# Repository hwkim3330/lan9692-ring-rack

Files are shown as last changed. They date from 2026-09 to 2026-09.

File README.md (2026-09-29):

# lan9692-ring-rack

LAN9692 링용 아크릴 랙. 9692가 3대이고, 한 대가 스택 하나의 바닥이다. 스택 3개는 모두 같은 구성이다.
판은 전부 **250 × 180 × 3 mm 투명 아크릴**이다. 이전(v1) 판과 외형, 기둥 위치, 9692 구멍, 팬 구멍이 같아서 서로 섞어 쓸 수 있다.

**3D 보기**
- 컬러 뷰어: <https://hwkim3330.github.io/lan9692-ring-rack/viewer/> (분해, 층 끄고 켜기, 아크릴 투명도 조절)
- [`stack.stl`](stack.stl): GitHub에서 누르면 돌려 볼 수 있다. 색이 없으니 포트 입구를 모양으로 파 뒀다

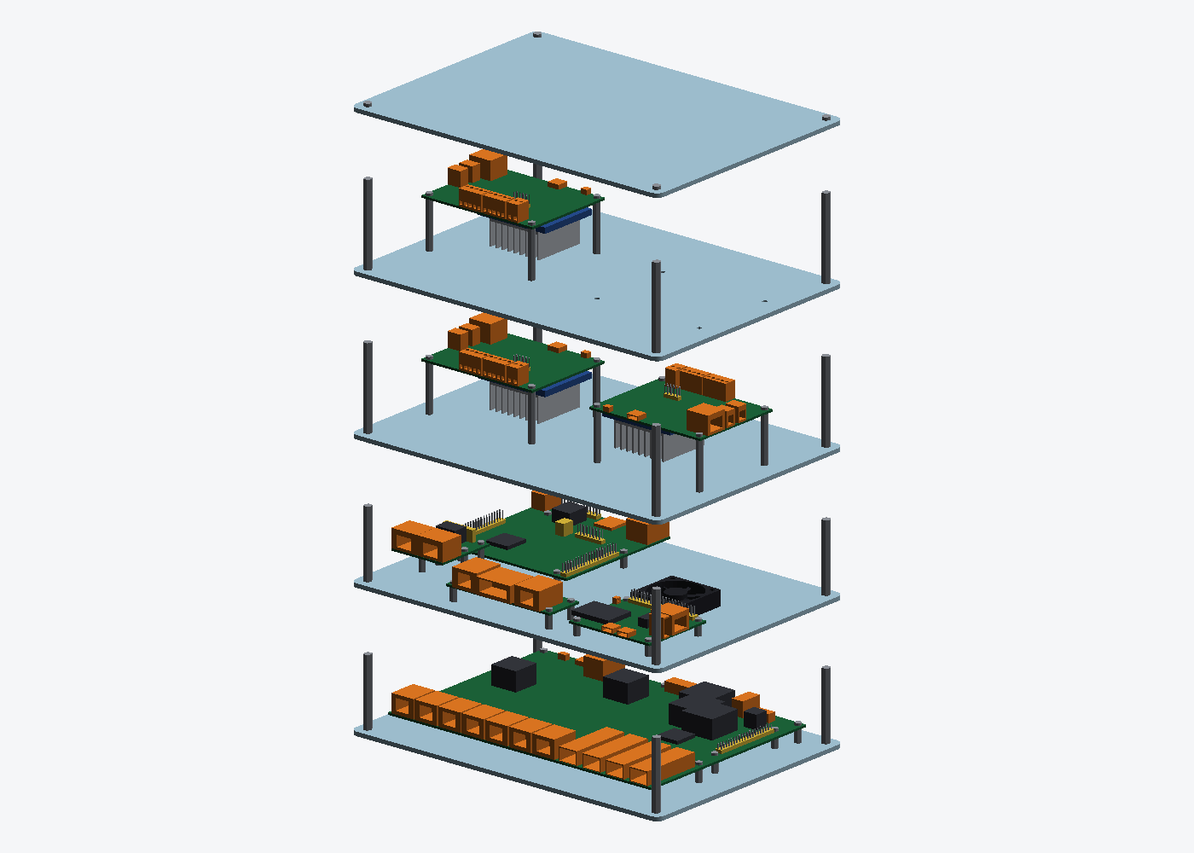
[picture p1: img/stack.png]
stack


| 층 | 판 | 올라가는 것 | 위층까지 |
|---|---|---|---:|
| 1 | `A-base` | LAN9692 (스탠드오프 10 mm) | 50 mm |
| 2 | `B-ecu` | TC397 · ESP32-S31 · 인젝션 모듈(RJ45 v2) · T1 커넥터 젠더 · 9692 팬 | 50 mm |
| 3 | `C-can` | CAN 보드 2장 (스탠드오프 35 mm) | 60 mm |
| 4 | `C-can` | CAN 보드 1장 (한 자리 여유) | 60 mm |
| 5 | `D-top` | 덮개 | — |

- 한 스택의 높이는 239 mm다(나사 머리 포함).
- **주문서: [`ORDER.md`](ORDER.md)** (아크릴 + 스탠드오프·나사·팬·전원 전부, [`BOM.csv`](BOM.csv)). 레이저 커팅은 [`order-dxf.zip`](order-dxf.zip)을 보낸다. 스택 3개 기준 총 15장이다.
  - A · B · D 각 3장
  - C 6장
- CAN 보드가 2장이면 `rack.py`의 `STACK`에서 `C-can` 하나를 빼면 된다. 그러면 12장이다.
- 레이저 커팅은 DXF로 주문한다. STL로는 주문하지 않는다.

## 배치

| 2층 | 3 · 4층 |
|---|---|
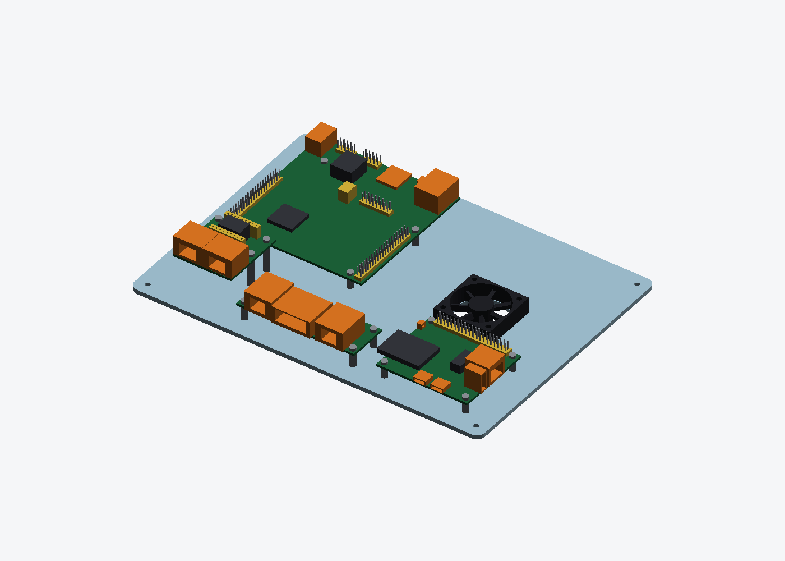
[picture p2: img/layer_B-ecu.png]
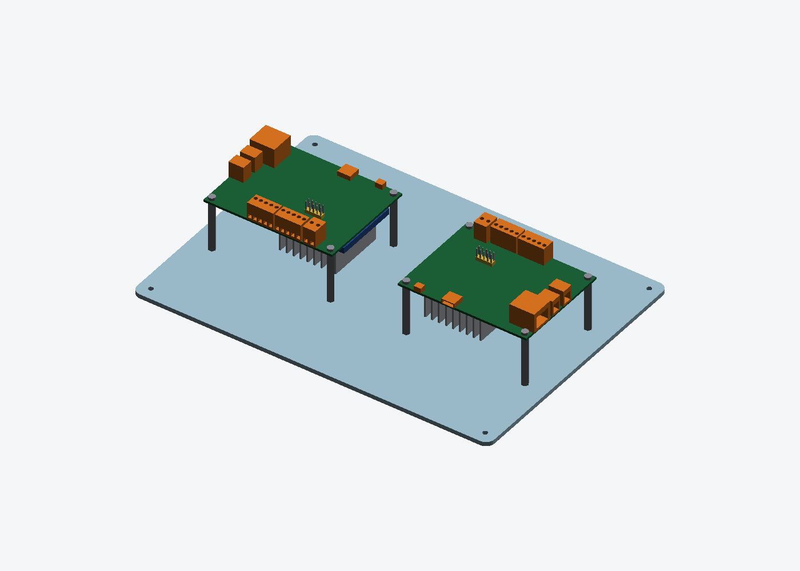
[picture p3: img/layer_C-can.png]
|  |  |

주황은 옆에서 꽂는 포트다. 입구가 커넥터 몸체에 파여 있어서, 색이 없는 STL에서도 어느 쪽으로 꽂는지 보인다. 노랑은 위에서 꽂는 헤더다.

**2층**
- TC397: POWER · SD · USB · RJ45가 뒤쪽 가장자리로 나간다. LIN · CAN은 위에서 꽂는 2x5 헤더다.
- 인젝션 모듈: 90° 돌려 놓아서 RJ45 2개가 앞쪽을 본다.
- T1 커넥터 젠더: 앞쪽 가운데 빈자리에 놓았다. MATEnet 2개와 TE 2305987-1이 앞쪽 가장자리로 나간다.
- ESP32-S31: USB-C 2개가 앞쪽, RJ45 · USB-A가 오른쪽을 본다. 모듈 안테나가 보드 왼쪽 밖으로 6 mm 나와 있어서 그 앞은 비워 뒀다.
- 팬: 9692 스위치 칩 바로 위, 판 구멍 자리에 있다.

**3 · 4층**
- CAN 보드는 세 면에 커넥터가 있다.
  - 왼쪽 면: CAN · LIN · POWER
  - 위쪽 면: ETH0 · T1S
  - 오른쪽 면: USB-C · RESET (실크의 A1…B8 핀 표기로 확인)
- 커넥터가 없는 면은 아래 면 하나뿐이다.
- 한 판에 두 장을 놓고, 빈 면끼리 46 mm 떨어져 마주 보게 했다. 그래서 **모든 커넥터가 판 가장자리로 나간다.**

| CAN 보드 | CAN · LIN · POWER | ETH · T1S | USB-C |
|---|---|---|---|
| 왼쪽 | 앞쪽 가장자리 | 왼쪽 가장자리 | 뒤쪽 가장자리 |
| 오른쪽 | 뒤쪽 가장자리 | 오른쪽 가장자리 | 앞쪽 가장자리 |

- 보드 밑에는 SoM과 20 mm 핀 방열판이 있다. 스탠드오프가 35 mm라 방열판 끝이 판에서 7.8 mm 떠 있다.

**검사**: `rack.py`는 모든 포트 앞으로 40 mm(가장자리가 더 가까우면 가장자리까지)를 쓸어서, 다른 보드·기둥·팬에 막히는지 본다. 지금 배치에서는 전부 통과한다. 보드 간격, 구멍 사이 아크릴 두께, 층별 높이 여유도 함께 검사한다.

## 치수 출처

모델은 보드 외형, 고정 구멍, 커넥터 블록까지만 그린다.

| 보드 | 출처 |
|---|---|
| LAN9692 EVB | Microchip Gerber/드릴(구멍), PnP(부품 위치) |
| TC397 AppKit | Infineon Application Kit Manual 그림 7-8(구멍), 그림 2-2(커넥터, ±0.5 mm) |
| ESP32-S31-Function-CoreBoard-1 | [Espressif 치수 DXF](https://dl.espressif.com/schematics/esp32-s31-function-coreboard-1-dimensions.dxf) |
| CAN 보드, 인젝션 모듈, T1 커넥터 젠더 | 각 보드의 제작 파일(KiCad) |

부품 높이 중 일부는 추정값이다. `boards.py`에서 `assumed`로 표시해 뒀다. 추정값이 틀려도 위층까지 5 mm 이상 여유가 남는다.

## 9692에서 5 V 따기

J4(2x20 확장 헤더)의 2번 · 4번 핀이 5 V다. 두 핀은 같은 레일이고, 둘을 합쳐 2 A까지 쓸 수 있다. 3.3 V는 1번 · 17번 핀, 2 A다. 출처는 EVB-LAN9692-LM User's Guide DS50003848, 표 5-14와 5.7절이다.

## 다시 만들기

```bash
pip3 install --break-system-packages trimesh shapely numpy pillow
python3 rack.py            # 검사 → DXF · zip → stack.stl · viewer/stack.glb → PNG
```

배치는 `rack.py`의 `PLATES`, 층 구성은 `STACK`에서 바꾼다.

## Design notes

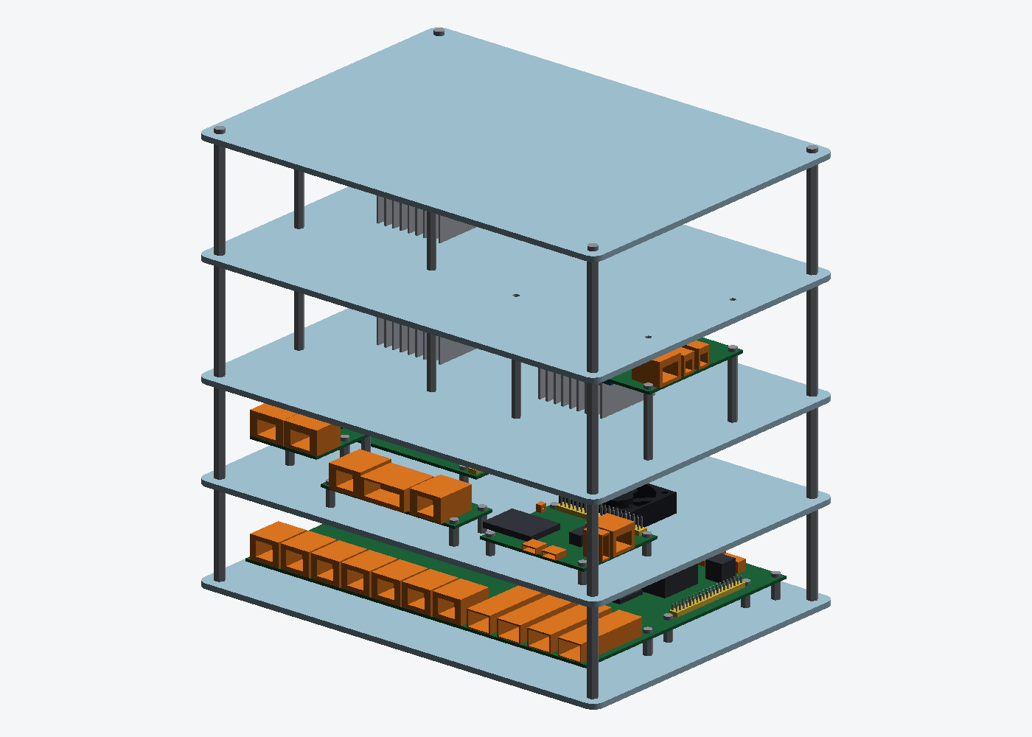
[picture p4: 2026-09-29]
img/stack_closed.png

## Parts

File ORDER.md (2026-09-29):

# 주문서 - 스택 3개

이 파일은 `rack.py`가 배치에서 직접 세어서 만든다. 손으로 고치지 말 것.

## 1. 레이저 커팅 (아크릴)

- 재질: **투명 캐스트 아크릴 3 mm**, 양면 보호필름 붙은 채로
- 판: **250 × 180 mm**, 모서리 R6. 도면은 DXF(mm, R12), 레이어 `CUT`만 있다
- 구멍 공차: 지름 +0.1 / -0 (M3 → Ø3.4, M2.5 → Ø2.9)
- 보낼 파일: `order-dxf.zip` 하나

| 도면 | 수량 | 구멍 |
|---|---:|---:|
| `dxf/A-base.dxf` | 3 | 12 |
| `dxf/B-ecu.dxf` | 3 | 25 |
| `dxf/C-can.dxf` | 6 | 12 |
| `dxf/D-top.dxf` | 3 | 4 |
| **합계** | **15** | |

## 2. 하드웨어

| 구분 | 품목 | 규격 | 수량 | 메모 |
|---|---|---|---:|---|
| column | hex standoff M/F | M3 x 50, male 6 mm | 24 | male end up; the stud crosses the plate above into the next standoff |
| column | hex standoff M/F | M3 x 60, male 6 mm | 24 | male end up; the stud crosses the plate above into the next standoff |
| column | screw, pan head | M3 x 8 | 12 | up through plate A into the first column standoff |
| column | nut | M3 | 12 | on the four studs above the top plate |
| column | rubber foot | self-adhesive, ~10 mm | 12 | under plate A |
| boards | hex standoff F/F | M3 x 10 | 24 | LAN9692 (board drill Ø3.048 - try an M3 by hand, use M2.5 if it binds) |
| boards | screw, pan head | M3 x 6 | 84 | down through the board |
| boards | screw, pan head | M3 x 8 | 84 | up through the plate |
| boards | washer, nylon | M3 | 84 | under every screw head that lands on acrylic |
| boards | hex standoff F/F | M3 x 8 | 24 | TC397, ESP32-S31 |
| boards | hex standoff F/F | M2.5 x 20 | 12 | FIM-RJ45v2 |
| boards | screw, pan head | M2.5 x 6 | 24 | down through the board |
| boards | screw, pan head | M2.5 x 8 | 24 | up through the plate |
| boards | washer, nylon | M2.5 | 24 | under every screw head that lands on acrylic |
| boards | hex standoff F/F | M2.5 x 10 | 12 | T1-Gender |
| boards | hex standoff F/F | M3 x 35 | 36 | KA7-UNO |
| fan | fan | 40 x 40 x 10 mm, 12 V | 3 | Noctua NF-A4x10 FLX; 32 mm hole pitch |
| fan | screw, pan head | M3 x 20 | 12 | down through the fan and plate B |
| fan | nut, nyloc | M3 | 12 | the fan is the one part that vibrates |
| power | DC adapter | 12 V 5 A, 5.5 x 2.5 mm, centre + | 3 | Mean Well GST60A12-P1M (P1M = 2.5 mm; P1J is 2.1 and contacts badly) |
| power | DC splitter | 1 female -> 2 male, 5.5 x 2.5 mm | 3 | NOT 5.5 x 2.1 |
| power | barrel socket to leads | female 5.5 x 2.5, 18 AWG | 3 | Tensility 10-02879 - the fan joins here. Meter which lead is the centre pin |

여분: 나사·너트·와셔는 10 % 더 사는 게 좋다. M3 x 60 스탠드오프가 없으면 30 + 30으로 이어도 된다.

## 3. 이미 있는 것 (주문 안 함)

- CAN 보드 방열판 20 mm (이미 붙어 있음)
- 보드 자체: LAN9692 EVB, TC397, ESP32-S31, CAN 보드, 인젝션 모듈 v2, T1 커넥터 젠더

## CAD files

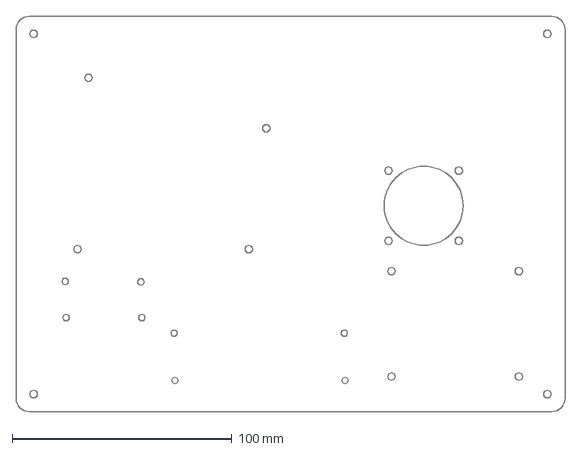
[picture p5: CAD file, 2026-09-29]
dxf/B-ecu.dxf
250.0 x 180.0 mm

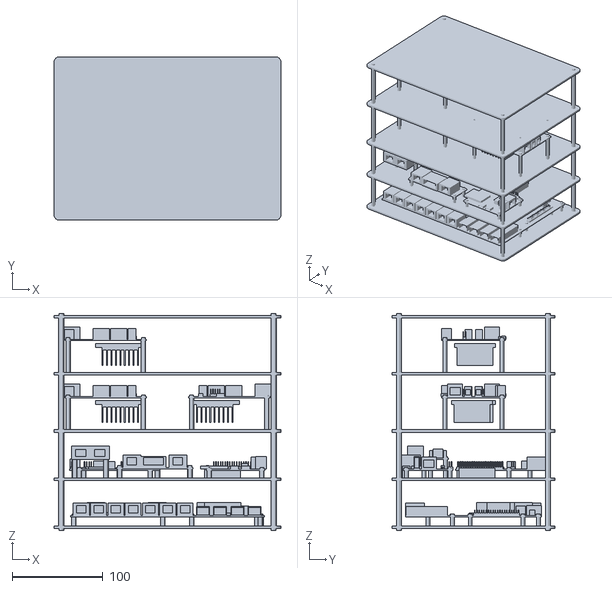
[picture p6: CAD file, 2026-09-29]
stack.stl
250.0 x 180.0 x 239.4

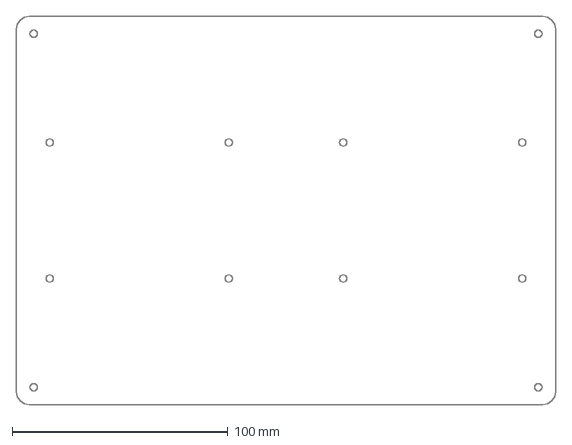
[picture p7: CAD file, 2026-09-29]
dxf/C-can.dxf
250.0 x 180.0 mm

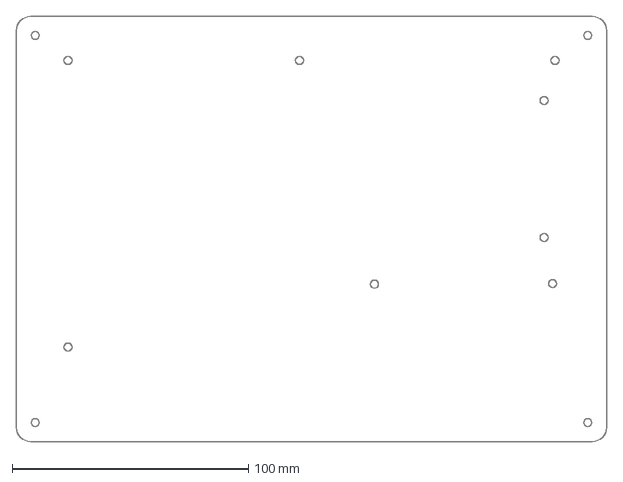
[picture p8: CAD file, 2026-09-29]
dxf/A-base.dxf
250.0 x 180.0 mm

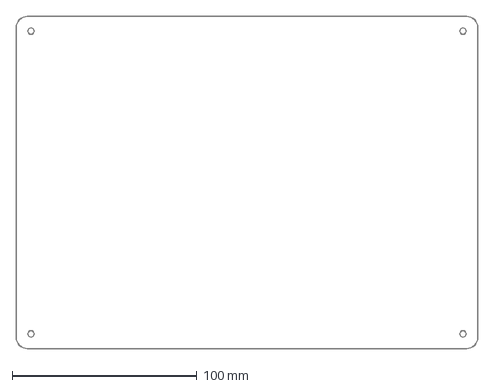
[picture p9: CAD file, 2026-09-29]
dxf/D-top.dxf
250.0 x 180.0 mm

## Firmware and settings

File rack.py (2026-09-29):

#!/usr/bin/env python3
"""Three acrylic stacks for the LAN9692 ring, one switch at the base of each.

    python3 rack.py            checks, DXF + order zip, STL, PNG
    python3 rack.py --no-png   skip the (slow) renders

Every plate is the same 250 x 180 x 3 mm clear acrylic with the same four
corner columns, so any upper plate bolts onto any stack. What a stack carries
is which plates you stack on it - see STACKS.
"""
import math
import os
import sys
import zipfile

import numpy as np
import trimesh
from shapely.geometry import Point, box
from shapely.ops import unary_union

import boards as B
import parts3d as P3
from render import render

HERE = os.path.dirname(os.path.abspath(__file__))

# --------------------------------------------------------------------------
# plate
PW, PH, T = 250.0, 180.0, 3.0      # the v1 plate - fixed, everything has to fit it
PLATE_R = 6.0
COLUMN_INSET = 8.0
M3 = 3.4
COLUMN_KEEPOUT = 6.0              # M3 M/F standoff, 5.5 mm across flats, + a hand
FAN = 40.0                        # Noctua NF-A4x10 on top of B, blowing down
FAN_H = 11.0
FAN_BORE = 36.0
FAN_PITCH = 32.0
BOARD_OFF = ((PW - B.LAN9692['size'][0]) / 2, (PH - B.LAN9692['size'][1]) / 2)
FAN_C = (BOARD_OFF[0] + B.LAN_U1[0], BOARD_OFF[1] + B.LAN_U1[1])

# --------------------------------------------------------------------------
# what goes on each plate: (board, cx, cy, rot CCW)
PLATES = {
    'A-base': [('LAN9692', PW / 2, PH / 2, 0)],
    # layer 2: TC397 connector row to the back rim; the injection module turned
    # so its two RJ45s face the front rim; the S31's USB-C to the front and
    # its RJ45/USB-A to the right rim; the 9692's fan over the switch die
    'B-ecu': [('TC397', 67.0, 120.0, 0),
              ('FIM-RJ45v2', 40.0, 40.0, 90),
              ('ESP32-S31', 200.0, 40.0, 0),
              # the T1 connector gender in the front gap, its three TE headers
              # to the front rim
              ('T1-Gender', 111.0, 25.0, 0)],
    # layer 3: two CAN boards per plate. The board has connectors on three
    # edges and one free one, so the two turn their free edges to each other
    # and every connector reaches a rim:
    #   left   CAN/LIN/POWER front, ETH/T1S left,  USB-C back
    #   right  CAN/LIN/POWER back,  ETH/T1S right, USB-C front
    'C-can': [('KA7-UNO', 57.0, 90.0, 90),
              ('KA7-UNO', 193.0, 90.0, 270)],
    'D-top': [],
}
FAN_ON = {'B-ecu'}

# layer gap above each plate kind (plate top to the next plate's underside)
GAP = {'A-base': 50.0, 'B-ecu': 50.0, 'C-can': 60.0}

STACK = ['A-base', 'B-ecu', 'C-can', 'C-can', 'D-top']   # bottom to top
FITTED = {3: [0]}                 # level -> boards fitted; the second CAN plate
                                  # carries the third board, room for a fourth
N_STACKS = 3                      # one per LAN9692 in the ring, all the same
PLUG_ROOM = 40.0                  # clear space a port needs in front of it,
                                  # or the rim if that is closer

MIN_GAP = 5.0                     # board to board, in plan
MIN_WEB = 2.5                     # acrylic between two cuts. The fan bore to its own
                                  # screw holes is 2.93, as cut and fitted in v1
MIN_AIR = 5.0                     # vertical


# --------------------------------------------------------------------------
# placement
def transform(board, cx, cy, rot):
    w, h = B.BOARDS[board]['size']
    c, s = round(math.cos(math.radians(rot))), round(math.sin(math.radians(rot)))

    def f(x, y):
        u, v = x - w / 2, y - h / 2
        return cx + c * u - s * v, cy + s * u + c * v
    return f


FACE_ROT = {0: {}, 90: {'-x': '-y', '-y': '+x', '+x': '+y', '+y': '-x'},
            180: {'-x': '+x', '+x': '-x', '-y': '+y', '+y': '-y'},
            270: {'-x': '+y', '+y': '+x', '+x': '-y', '-y': '-x'}}


def rect(f, x0, y0, x1, y1):
    (ax, ay), (bx, by) = f(x0, y0), f(x1, y1)
    return (min(ax, bx), min(ay, by), max(ax, bx), max(ay, by))


def placed(kind):
    """-> list of dict(board, pcb, parts[(name, rect, h, face)], holes[(x,y,d)])"""
    out = []
    for board, cx, cy, rot in PLATES[kind]:
        d = B.BOARDS[board]
        f = transform(board, cx, cy, rot)
        w, h = d['size']
        parts = [(n, rect(f, x0, y0, x1, y1), ht,
                  FACE_ROT[rot].get(face, face) if face else None, src)
                 for n, x0, y0, x1, y1, ht, face, src in d['parts']]
        out.append(dict(board=board, rot=rot, pcb=rect(f, 0, 0, w, h), parts=parts,
                        under=[(n, rect(f, x0, y0, x1, y1), zt, zb)
                               for n, x0, y0, x1, y1, zt, zb in d['under']],
                        holes=[f(x, y) + (d['hole_d'],) for x, y in d['holes']],
                        f=f))
    return out


def columns():
    return [(x, y) for x in (COLUMN_INSET, PW - COLUMN_INSET)
            for y in (COLUMN_INSET, PH - COLUMN_INSET)]


def features(kind):
    """Every circle cut in a plate: (x, y, d)."""
    f = [(x, y, M3) for x, y in columns()]
    if kind in FAN_ON:
        f.append((FAN_C[0], FAN_C[1], FAN_BORE))
        f += [(FAN_C[0] + sx * FAN_PITCH / 2, FAN_C[1] + sy * FAN_PITCH / 2, M3)
              for sx in (-1, 1) for sy in (-1, 1)]
    for p in placed(kind):
        f += p['holes']
    return f


# --------------------------------------------------------------------------
# checks
def footprint(p):
    return unary_union([box(*p['pcb'])] + [box(*r) for _, r, *_ in p['parts']]
                       + [box(*r) for _, r, *_ in p['under']])


def check_plate(kind):
    rows, ports = [], []
    ps = placed(kind)
    plate = box(0, 0, PW, PH)
    keep = [Point(x, y).buffer(COLUMN_KEEPOUT) for x, y in columns()]
    fan = box(FAN_C[0] - FAN / 2, FAN_C[1] - FAN / 2, FAN_C[0] + FAN / 2,
              FAN_C[1] + FAN / 2) if kind in FAN_ON else None

    def need(label, mm, want):
        rows.append((label, mm, want, mm >= want))

    fps = [footprint(p) for p in ps]
    for i in range(len(ps)):
        name = f"{ps[i]['board']}#{i}"
        need(f'{name} inside the plate', min(
            fps[i].bounds[0], fps[i].bounds[1], PW - fps[i].bounds[2], PH - fps[i].bounds[3]), 0.0)
        need(f'{name} to the corner columns', min(fps[i].distance(k) for k in keep), 0.0)
        if fan is not None:
            need(f'{name} to the fan', fps[i].distance(fan), MIN_GAP)
        for j in range(i + 1, len(ps)):
            need(f"{name} to {ps[j]['board']}#{j}", fps[i].distance(fps[j]), MIN_GAP)
    # acrylic webs
    cuts = features(kind)
    worst = min((math.hypot(a[0] - b[0], a[1] - b[1]) - a[2] / 2 - b[2] / 2)
                for i, a in enumerate(cuts) for b in cuts[i + 1:])
    need('thinnest web between two holes', worst, MIN_WEB)
    need('thinnest web to the plate edge',
         min(min(x, y, PW - x, PH - y) - d / 2 for x, y, d in cuts), MIN_WEB)
    # ports: sweep each port's face out to the rim and see what it meets
    for i, p in enumerate(ps):
        others = [fps[j] for j in range(len(ps)) if j != i] + keep + ([fan] if fan else [])
        for n, (x0, y0, x1, y1), h, face, src in p['parts']:
            if face in (None, 'top'):
                continue
            to_rim = {'-x': x0, '+x': PW - x1, '-y': y0, '+y': PH - y1}[face]
            r = min(PLUG_ROOM, max(to_rim, 0.0))
            lane = {'-x': (x0 - r, y0, x0, y1), '+x': (x1, y0, x1 + r, y1),
                    '-y': (x0, y0 - r, x1, y0), '+y': (x0, y1, x1, y1 + r)}[face]
            if lane[2] - lane[0] <= 0 or lane[3] - lane[1] <= 0:
                blocked = False             # already at or past the rim
            else:
                blocked = any(box(*lane).intersects(o) for o in others)
            ports.append((f"{p['board']}#{i} {n}", face, to_rim, not blocked))
    return rows, ports


def vertical(kind):
    """Clearances in the layer ABOVE this plate, and under its boards."""
    rows = []
    gap = GAP.get(kind)
    for i, p in enumerate(placed(kind)):
        d = B.BOARDS[p['board']]
        top = d['standoff'] + B.PCB_T + max(h for _, _, _, _, _, h, _, _ in d['parts'])
        if gap:
            rows.append((f"{p['board']}#{i} tallest part -> plate above", gap - top, MIN_AIR))
        for n, _, _, zb in p['under']:
            rows.append((f"{p['board']}#{i} {n} -> its own plate", d['standoff'] - zb, MIN_AIR))
    if kind in FAN_ON:
        rows.append(('fan -> plate above', gap - FAN_H, MIN_AIR))
    if kind == 'A-base':
        rows.append(('LAN9692 tallest part -> fan underside',
                     gap - B.LAN9692['standoff'] - B.PCB_T - 14.0, MIN_AIR))
    return [(l, mm, w, mm >= w) for l, mm, w in rows]


def run_checks(verbose=True):
    ok = True
    for kind in PLATES:
        rows, ports = check_plate(kind)
        rows += vertical(kind)
        bad = [r for r in rows if not r[3]] + [p for p in ports if not p[3]]
        ok &= not bad
        if not verbose:
            continue
        print(f'\n{kind}: {"OK" if not bad else "FAIL"}')
        for label, mm, want, good in rows:
            print(f'    {label:52s} {mm:8.2f}  >= {want:<4}' + ('' if good else '  <-- FAIL'))
        for label, face, to_rim, clear in ports:
            print(f'    port {label:40s} {face:>3}  {to_rim:6.1f} mm to rim  '
                  + ('clear' if clear else 'BLOCKED'))
    return ok


# --------------------------------------------------------------------------
# DXF
class Dxf:
    def __init__(self):
        self.e = []

    def line(self, x1, y1, x2, y2):
        self.e.append(f"0\nLINE\n8\nCUT\n10\n{x1:.4f}\n20\n{y1:.4f}\n30\n0.0\n"
                      f"11\n{x2:.4f}\n21\n{y2:.4f}\n31\n0.0\n")

    def arc(self, cx, cy, r, a0, a1):
        self.e.append(f"0\nARC\n8\nCUT\n10\n{cx:.4f}\n20\n{cy:.4f}\n30\n0.0\n"
                      f"40\n{r:.4f}\n50\n{a0:.4f}\n51\n{a1:.4f}\n")

    def circle(self, cx, cy, r):
        self.e.append(f"0\nCIRCLE\n8\nCUT\n10\n{cx:.4f}\n20\n{cy:.4f}\n30\n0.0\n40\n{r:.4f}\n")

    def rounded_rect(self, w, h, r):
        self.line(r, 0, w - r, 0); self.line(r, h, w - r, h)
        self.line(0, r, 0, h - r); self.line(w, r, w, h - r)
        self.arc(w - r, h - r, r, 0, 90); self.arc(r, h - r, r, 90, 180)
        self.arc(r, r, r, 180, 270); self.arc(w - r, r, r, 270, 360)

    def save(self, path):
        with open(path, 'w') as f:
            f.write("0\nSECTION\n2\nHEADER\n9\n$INSUNITS\n70\n4\n0\nENDSEC\n"
                    "0\nSECTION\n2\nENTITIES\n" + ''.join(self.e) + "0\nENDSEC\n0\nEOF\n")


def write_dxf(kind, path):
    d = Dxf()
    d.rounded_rect(PW, PH, PLATE_R)
    for x, y, dia in features(kind):
        d.circle(x, y, dia / 2)
    d.save(path)


# --------------------------------------------------------------------------
# 3D
COL = {'plate': (170, 205, 222), 'pcb': (30, 105, 60), 'port': (235, 125, 35),
       'top': (225, 190, 60), 'part': (55, 57, 64), 'som': (40, 80, 150),
       'sink': (190, 195, 202), 'metal': (150, 155, 162), 'fan': (35, 36, 42),
       'ka7': (30, 105, 60)}


def tagged(m, c):
    m.visual.face_colors = np.tile(np.array(list(COL[c]) + [255], np.uint8), (len(m.faces), 1))
    return m


def slab(r, z0, z1, c):
    x0, y0, x1, y1 = r
    m = trimesh.creation.box(extents=(x1 - x0, y1 - y0, z1 - z0))
    m.apply_translation(((x0 + x1) / 2, (y0 + y1) / 2, (z0 + z1) / 2))
    return tagged(m, c)


def post(x, y, z0, z1, d=5.5):
    m = trimesh.creation.cylinder(radius=d / 2, height=z1 - z0, sections=6)
    m.apply_translation((x, y, (z0 + z1) / 2))
    return tagged(m, 'metal')


def plate_poly(kind):
    r = PLATE_R
    outline = box(r, r, PW - r, PH - r).buffer(r, resolution=16)
    return outline.difference(unary_union(
        [Point(x, y).buffer(d / 2, resolution=24) for x, y, d in features(kind)]))


def plate_mesh(kind, z):
    m = trimesh.creation.extrude_polygon(plate_poly(kind), T)
    m.apply_translation((0, 0, z))
    return tagged(m, 'plate')


def board_meshes(p, z_plate_top, detail=True):
    d = B.BOARDS[p['board']]
    zp = z_plate_top + d['standoff']
    top = zp + B.PCB_T
    out = [slab(p['pcb'], zp, top, 'pcb')]
    for n, r, h, face, src in p['parts']:
        if face == 'top':
            bars, pins = P3.header(n, r, top, h)
            out += [tagged(m, 'top') for m in bars] + [tagged(m, 'metal') for m in pins]
        elif face:
            out += [tagged(m, 'port') for m in P3.side_connector(n, r, top, h, face)]
        else:
            out.append(slab(r, top, top + h, 'part'))
    for n, r, zt, zb in p['under']:
        if 'heatsink' in n:
            out += [tagged(m, 'sink') for m in P3.heatsink(r, zp - zt, zp - zb)]
        else:
            out.append(slab(r, zp - zb, zp - zt, 'som'))
    for x, y, _ in p['holes']:
        out.append(post(x, y, z_plate_top, zp, d=5.0))
        out.append(tagged(P3.screw_head(x, y, top, d=4.6, hh=1.8), 'metal'))
    return out


def layer_meshes(kind, z, detail=True, fitted=None):
    """-> [(group, mesh)]; group names what the viewer can hide or tint."""
    parts = [('plate', plate_mesh(kind, z))]
    if kind in FAN_ON:
        parts += [('fan', tagged(m, 'fan')) for m in P3.fan(FAN_C[0], FAN_C[1], z + T, FAN, FAN_H)]
    for i, p in enumerate(placed(kind)):
        if fitted is None or i in fitted:
            parts += [(p['board'], m) for m in board_meshes(p, z + T)]
    return parts


def stack_parts(explode=0.0):
    """-> [(level, group, mesh)] for the whole stack, bottom to top."""
    parts, z = [], 0.0
    for lvl, kind in enumerate(STACK):
        parts += [(lvl, g, m) for g, m in layer_meshes(kind, z, fitted=FITTED.get(lvl))]
        if kind in GAP:
            nxt = z + T + GAP[kind]
            for x, y in columns():
                parts.append((lvl, 'column', post(x, y, z + T, nxt, d=6.0)))
            z = nxt + explode
        else:
            for x, y in columns():
                parts.append((lvl, 'column', tagged(P3.screw_head(x, y, z + T), 'metal')))
    for x, y in columns():
        parts.append((0, 'column', tagged(P3.screw_head(x, y, 0.0, up=False), 'metal')))
    return parts


def stack_mesh(explode=0.0):
    return trimesh.util.concatenate([m for _, _, m in stack_parts(explode)])


def export_glb(path):
    """One node per (level, group, colour), so the viewer can explode and tint."""
    scene = trimesh.Scene()
    groups = {}
    for lvl, g, m in stack_parts():
        c = tuple(m.visual.face_colors[0][:3])
        groups.setdefault((lvl, g, c), []).append(m)
    for (lvl, g, c), ms in groups.items():
        m = trimesh.util.concatenate(ms)
        m.visual = trimesh.visual.TextureVisuals(material=trimesh.visual.material.PBRMaterial(
            baseColorFactor=[c[0] / 255, c[1] / 255, c[2] / 255, 1.0],
            metallicFactor=0.6 if g in ('column',) else 0.0, roughnessFactor=0.55))
        scene.add_geometry(m, node_name=f'L{lvl}|{g}|{c[0]}_{c[1]}_{c[2]}',
                           geom_name=f'L{lvl}|{g}|{c[0]}_{c[1]}_{c[2]}')
    scene.export(path)


# --------------------------------------------------------------------------
# order: every screw, standoff and plate, counted from the layout itself
def bom():
    """-> [(group, item, spec, qty, note)] for N_STACKS stacks."""
    from collections import Counter
    c = Counter()
    notes = {}

    def add(group, item, spec, n, note=''):
        c[(group, item, spec)] += n * N_STACKS
        if note:
            notes[(group, item, spec)] = note

    for kind in PLATES:
        n = STACK.count(kind)
        if n:
            add('acrylic', f'plate {kind}', f'clear cast acrylic 3 mm, {PW:.0f} x {PH:.0f}, R{PLATE_R:.0f}',
                n, f'dxf/{kind}.dxf')
    # columns: M/F, male end up; each stud crosses the plate above it and
    # threads into the next standoff, so one hole per corner does both joints
    for kind in STACK:
        if kind in GAP:
            add('column', 'hex standoff M/F', f'M3 x {GAP[kind]:.0f}, male 6 mm', 4,
                'male end up; the stud crosses the plate above into the next standoff')
    add('column', 'screw, pan head', 'M3 x 8', 4, 'up through plate A into the first column standoff')
    add('column', 'nut', 'M3', 4, 'on the four studs above the top plate')
    add('column', 'rubber foot', 'self-adhesive, ~10 mm', 4, 'under plate A')
    # boards: F/F standoffs, a screw from under the plate and one from above
    for lvl, kind in enumerate(STACK):
        f = FITTED.get(lvl)
        for i, p in enumerate(placed(kind)):
            if f is not None and i not in f:
                continue
            d = B.BOARDS[p['board']]
            m = 'M2.5' if d['hole_d'] < 3.2 else 'M3'
            k = len(d['holes'])
            key = ('boards', 'hex standoff F/F', f"{m} x {d['standoff']:.0f}")
            who = notes.get(key, '')
            if p['board'] not in who:
                who = (who + ', ' if who else '') + p['board']
            if p['board'] == 'LAN9692':
                who += ' (board drill Ø3.048 - try an M3 by hand, use M2.5 if it binds)'
            add(*key, k, who)
            add('boards', 'screw, pan head', f'{m} x 6', k, 'down through the board')
            add('boards', 'screw, pan head', f'{m} x 8', k, 'up through the plate')
            add('boards', 'washer, nylon', m, k, 'under every screw head that lands on acrylic')
    # fan over the switch die, on top of the B plate
    add('fan', 'fan', '40 x 40 x 10 mm, 12 V', 1, 'Noctua NF-A4x10 FLX; 32 mm hole pitch')
    add('fan', 'screw, pan head', 'M3 x 20', 4, 'down through the fan and plate B')
    add('fan', 'nut, nyloc', 'M3', 4, 'the fan is the one part that vibrates')
    add('power', 'DC adapter', '12 V 5 A, 5.5 x 2.5 mm, centre +', 1,
        'Mean Well GST60A12-P1M (P1M = 2.5 mm; P1J is 2.1 and contacts badly)')
    add('power', 'DC splitter', '1 female -> 2 male, 5.5 x 2.5 mm', 1, 'NOT 5.5 x 2.1')
    add('power', 'barrel socket to leads', 'female 5.5 x 2.5, 18 AWG', 1,
        'Tensility 10-02879 - the fan joins here. Meter which lead is the centre pin')
    return [(g, i, s_, q, notes.get((g, i, s_), '')) for (g, i, s_), q in c.items()]


def write_order():
    rows = bom()
    with open(os.path.join(HERE, 'BOM.csv'), 'w') as f:
        f.write('group,item,spec,qty,note\n')
        for r in rows:
            f.write(','.join(f'"{x}"' if isinstance(x, str) and (',' in x) else str(x) for x in r) + '\n')
    md = [f'# 주문서 - 스택 {N_STACKS}개\n',
          f'이 파일은 `rack.py`가 배치에서 직접 세어서 만든다. 손으로 고치지 말 것.\n',
          '## 1. 레이저 커팅 (아크릴)\n',
          f'- 재질: **투명 캐스트 아크릴 3 mm**, 양면 보호필름 붙은 채로',
          f'- 판: **{PW:.0f} × {PH:.0f} mm**, 모서리 R{PLATE_R:.0f}. 도면은 DXF(mm, R12), 레이어 `CUT`만 있다',
          '- 구멍 공차: 지름 +0.1 / -0 (M3 → Ø3.4, M2.5 → Ø2.9)',
          '- 보낼 파일: `order-dxf.zip` 하나\n',
          '| 도면 | 수량 | 구멍 |', '|---|---:|---:|']
    for kind in PLATES:
        n = N_STACKS * STACK.count(kind)
        if n:
            md.append(f'| `dxf/{kind}.dxf` | {n} | {len(features(kind))} |')
    md.append(f'| **합계** | **{N_STACKS * len(STACK)}** | |\n')
    md.append('## 2. 하드웨어\n')
    md.append('| 구분 | 품목 | 규격 | 수량 | 메모 |')
    md.append('|---|---|---|---:|---|')
    for g, i, s_, q, n in rows:
        if g != 'acrylic':
            md.append(f'| {g} | {i} | {s_} | {q} | {n} |')
    md.append('\n여분: 나사·너트·와셔는 10 % 더 사는 게 좋다. M3 x 60 스탠드오프가 없으면 30 + 30으로 이어도 된다.\n')
    md.append('## 3. 이미 있는 것 (주문 안 함)\n')
    md.append('- CAN 보드 방열판 20 mm (이미 붙어 있음)')
    md.append('- 보드 자체: LAN9692 EVB, TC397, ESP32-S31, CAN 보드, 인젝션 모듈 v2, T1 커넥터 젠더\n')
    open(os.path.join(HERE, 'ORDER.md'), 'w').write('\n'.join(md))


# --------------------------------------------------------------------------
def main():
    for sub in ('dxf', 'img', 'viewer'):
        os.makedirs(os.path.join(HERE, sub), exist_ok=True)
    ok = run_checks()

    print(f'\norder: {N_STACKS} stacks, 250 x 180 x 3 mm clear acrylic')
    made = []
    for kind in PLATES:
        p = os.path.join(HERE, 'dxf', f'{kind}.dxf')
        write_dxf(kind, p)
        made.append(p)
        print(f'  {kind:8s} x{N_STACKS * STACK.count(kind)}   {len(features(kind))} holes')
    print(f'  total    x{N_STACKS * len(STACK)}')
    with zipfile.ZipFile(os.path.join(HERE, 'order-dxf.zip'), 'w', zipfile.ZIP_DEFLATED) as z:
        for p in made:
            info = zipfile.ZipInfo(os.path.basename(p), date_time=(2026, 1, 1, 0, 0, 0))
            info.compress_type = zipfile.ZIP_DEFLATED
            info.external_attr = 0o644 << 16
            z.writestr(info, open(p, 'rb').read())

    write_order()
    m = stack_mesh()
    m.export(os.path.join(HERE, 'stack.stl'))
    export_glb(os.path.join(HERE, 'viewer', 'stack.glb'))
    print(f'\nstack.stl  {m.extents.round(1).tolist()} mm, {len(m.faces)} faces')

    if '--no-png' not in sys.argv:
        for kind in PLATES:
            if PLATES[kind]:
                mm = trimesh.util.concatenate([m for _, m in layer_meshes(kind, 0.0)])
                render(mm, elev=38, azim=-35).save(os.path.join(HERE, 'img', f'layer_{kind}.png'))
        render(stack_mesh(explode=45.0), elev=20, azim=-40).save(os.path.join(HERE, 'img', 'stack.png'))
        render(stack_mesh(), elev=22, azim=-40).save(os.path.join(HERE, 'img', 'stack_closed.png'))
    print('\n' + ('ALL CHECKS OK' if ok else 'SOME CHECKS FAILED'))
    return 0 if ok else 1


if __name__ == '__main__':
    sys.exit(main())

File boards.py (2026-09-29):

"""Every board on the rack: outline, mounting holes, and the parts that matter.

Coordinates are millimetres from each board's bottom-left corner, top view,
y up. A part is (name, x0, y0, x1, y1, height, face, source):

    height  above the PCB's top face. Negative-z parts (under the board) are in
            UNDER instead.
    face    '-x' '+x' '-y' '+y'  the edge a cable plugs in from, or
            'top'                plugged from above (pin headers, terminal bars)
            None                 not a connector
    source  where the numbers come from. 'assumed' means the height only; no
            position here is a guess unless it says so.

Port bodies are allowed to run past the board edge - that is where they are
on the real boards (the S31's module antenna, most USB and RJ45 jacks).
"""

# --------------------------------------------------------------------------
# Microchip EV09P11A, EVB-LAN9692-LM. Outline and holes from the released
# Gerber/Excellon (tool T23, Ø3.048); parts from the pick-and-place file.
LAN9692 = dict(
    size=(213.36, 149.86), hole_d=3.4, standoff=10.0,
    holes=[(3.556, 146.304), (101.600, 146.304), (209.804, 146.304),
           (205.187, 129.330), (205.187, 71.330), (208.788, 51.816),
           (133.350, 51.562), (3.556, 24.892)],
    parts=[
        # front edge: 7 x MATEnet (TE 9-2304372-9) + 4 x SFP+ cages
        *[(f'MATEnet P{i + 1}', x - 8.875, 0.0, x + 8.875, 21.1, 13.5, '-y', 'PnP + TE drawing')
          for i, x in enumerate((11.684, 30.734, 49.784, 68.834, 87.884, 106.934, 125.984))],
        *[(f'SFP+ {c}', x - 7.25, 0.4, x + 7.25, 46.4, 9.8, '-y', 'PnP + SFP MSA')
          for c, x in zip('ABCD', (145.6, 164.6, 183.6, 202.6))],
        # rear edge
        ('RJ45 J33', 50.863, 128.436, 66.743, 149.436, 13.5, '+y', 'PnP'),
        ('USB-C J30 console', 33.262, 141.116, 42.262, 148.616 + 0.8, 3.2, '+y', 'PnP'),
        ('OCuLink J21', 107.305, 139.621, 129.305, 147.621 + 0.8, 7.0, '+y', 'PnP, height assumed'),
        ('12 V jack J23', 166.783, 133.457, 175.783, 147.957 + 1.9, 11.0, '+y', 'PnP + PJ-002BH'),
        ('switch SW3', 182.110, 136.767, 194.110, 142.767, 6.0, '+y', 'PnP, height assumed'),
        ('reset SW2', 18.844, 142.018, 24.844, 146.018, 4.0, '+y', 'PnP, height assumed'),
        # interior
        ('expansion J4 2x20 (5V on pins 2, 4)', 202.65, 74.93, 207.73, 125.73, 5.84, 'top', 'PnP'),
        ('switch U1', 158.81, 70.19, 175.81, 87.19, 2.5, None, 'PnP'),
        ('DC-DC U3', 139.068, 115.08, 164.068, 140.08, 14.0, None, 'PnP, height assumed'),
        ('DC-DC U14', 147.61, 95.27, 172.61, 120.27, 14.0, None, 'PnP, height assumed'),
        ('DC-DC U10', 162.38, 89.95, 187.38, 114.95, 14.0, None, 'PnP, height assumed'),
        ('DC-DC U20', 85.44, 106.34, 105.44, 126.34, 14.0, None, 'PnP, height assumed'),
        ('DC-DC U17', 17.93, 78.43, 37.93, 98.43, 14.0, None, 'PnP, height assumed'),
        ('cap C324', 186.008, 121.921, 196.308, 132.221, 10.2, None, 'PnP'),
    ],
    under=[],
)
LAN_U1 = (167.31, 78.69)          # switch die centre, PnP. The fan is bored over it.

# --------------------------------------------------------------------------
# Infineon AURIX Application Kit TC3X7 V2.0. Holes from figure 7-8 of the
# Application Kit Manual; connector spans read off figure 2-2 (top placement)
# at 5.37 px/mm against the 100 mm outline - good to about ±0.5 mm.
TC397 = dict(
    size=(100.0, 100.0), hole_d=3.4, standoff=8.0,
    holes=[(11.0, 4.0), (89.0, 4.0), (96.99, 59.0), (16.0, 82.0)],
    parts=[
        ('POWER X101 barrel', 0.6, 84.2, 11.7, 100.8, 11.0, '+y', 'manual fig 2-2'),
        ('LIN X203 2x5', 15.8, 93.5, 27.6, 98.7, 8.5, 'top', 'manual fig 2-2'),
        ('CAN X202 2x5', 34.4, 93.5, 45.6, 98.7, 8.5, 'top', 'manual fig 2-2'),
        ('SD card X205', 51.2, 84.2, 65.7, 100.3, 2.0, '+y', 'manual fig 2-2'),
        ('USB BU301', 72.3, 95.3, 80.1, 101.2, 3.0, '+y', 'manual fig 2-2'),
        ('RJ45 X204', 82.1, 79.0, 99.3, 100.5, 13.5, '+y', 'manual fig 2-2'),
        ('JTAG X301 2x8', 55.5, 60.9, 76.9, 65.5, 8.5, 'top', 'manual fig 2-2'),
        ('DAP X302', 43.0, 57.0, 50.0, 66.0, 8.5, 'top', 'manual fig 2-2'),
        ('header X103 2x20', 1.1, 2.2, 6.1, 53.4, 8.5, 'top', 'manual fig 2-2'),
        ('header X102 2x20', 93.7, 1.3, 98.5, 52.5, 8.5, 'top', 'manual fig 2-2'),
        ('buzzer LS101', 26.6, 73.0, 41.5, 89.4, 9.0, None, 'manual fig 2-2, height assumed'),
        ('MCU U101', 21.0, 16.2, 38.7, 34.0, 2.5, None, 'manual fig 2-2'),
    ],
    under=[],
)

# --------------------------------------------------------------------------
# Espressif ESP32-S31-Function-CoreBoard-1 (v1.0). Everything from the
# published dimension DXF: outline and 58 x 48 hole rectangle from its DIMENSION
# entities, connector bodies from its silkscreen outlines.
#   https://dl.espressif.com/schematics/esp32-s31-function-coreboard-1-dimensions.dxf
# The WROOM-3 module hangs 6.00 mm past the left edge - the drawing dimensions
# it - so the antenna end needs nothing parked in front of it.
S31 = dict(
    size=(65.0, 55.0), hole_d=3.4, standoff=8.0,
    holes=[(3.5, 3.5), (61.5, 3.5), (3.5, 51.5), (61.5, 51.5)],
    parts=[
        ('module ESP32-S31-WROOM-3', -6.0, 9.2, 24.0, 31.2, 3.2, None, 'dimension DXF'),
        ('USB-C UART', 26.92, -0.8, 35.86, 7.38, 3.3, '-y', 'dimension DXF'),
        ('USB-C DBG', 39.22, -0.8, 48.16, 7.38, 3.3, '-y', 'dimension DXF'),
        ('RJ45 1GbE', 49.24, 20.05, 66.5, 36.55, 13.5, '+x', 'dimension DXF'),
        ('USB-A HS', 54.51, 12.12, 66.5, 17.84, 14.0, '+x', 'dimension DXF, stands on edge - height assumed'),
        ('magnetics', 39.0, 20.19, 46.1, 35.29, 6.0, None, 'dimension DXF'),
        ('header J2 2x20 (5V, G at the right end)', 6.34, 49.21, 58.66, 54.79, 8.5, 'top', 'dimension DXF'),
        ('speaker SPK', 0.0, 41.5, 3.4, 45.5, 4.0, '-x', 'dimension DXF, approximate'),
    ],
    under=[],
)
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

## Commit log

2026-09-29 Acrylic rack for a three-switch LAN9692 ring
    Three identical stacks, one LAN9692 at the base of each: layer 2 carries
    a TC397, an ESP32-S31 and an RJ45 fault injection module, layer 3 three
    CAN boards turned a quarter each so every connector faces a rim. Boards
    are drawn as outline, holes and connector blocks. Every port is checked
    for 40 mm of clear room.
    [A-base.dxf, B-ecu.dxf, C-can.dxf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]
2026-09-29 Three-sided CAN boards, free edges to the middle; connector mouths; colour viewer
    The CAN carrier also has a USB-C and RESET on its right edge (silkscreen
    A1..B8), so only one edge is free. Three of them need 300 x 210 plates to
    give every port 40 mm of plug room. The injection module turns to face the
    front. Connectors now have their openings cut in, headers their pins, the
    heatsink its fins and the fan its bore, so the grey STL shows which way
    each port opens. viewer/ is a three.js page over a coloured GLB.
    [A-base.dxf, B-ecu.dxf, C-can.dxf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]
2026-09-29 Back to the v1 250 x 180 plate; two CAN boards per plate, free edges facing
    Growing the plate broke compatibility with the plates already cut. Two
    three-sided CAN boards per plate, free edges 46 mm apart, put every
    connector on a rim; a second CAN plate carries the third board.
    [A-base.dxf, B-ecu.dxf, C-can.dxf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]
2026-09-29 Layer 2: T1 connector gender in the front gap, headers to the front rim
    [B-ecu.dxf, stack.stl]
2026-09-29 ORDER.md and BOM.csv, counted from the layout
    Plates, column and board standoffs, screws, washers, fan and power, for
    three stacks. Generated by rack.py so the counts follow any layout change.
    [BOM.csv]
2026-10-30 Printable plates: the DXF plates as A1 prints (same holes, rim underneath, 40 % infill)
2026-10-30 Printed plates: flat 3 mm, no rim underneath, 100 % infill
2026-10-30 Printed plates: back to 40 % infill (flat plate is sturdy enough)
2026-11-01 Print audit of the printable plates; ignore the derived print/ folder
